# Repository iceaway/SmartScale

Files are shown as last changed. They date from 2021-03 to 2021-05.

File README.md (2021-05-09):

# SmartScale
## What is it
What is SmartScale? The idea for a "smart scale" came about when I was 
grinding coffee and got tired of moving the portafilter between my grinder
and scale to measure my exact amount. I figured it should be quite easy to
hook up an ESP8266 to a load cell for measuring the amount of coffee, and
control the grinder directly in some way. For this initial prototype I have
connected my ESP8266 to a 1 kg load cell via a cheap HX711 breakout board,
and to a relay for controlling the grinder. The way it operates is that
I will have to hold the manual grind button on the grinder, and the "SmartScale"
will cut the power to the grinder when the desired amount is measured. The 
mains power stuff is enclosed in a plastic box, and the load cell is mounted to
a very simple 3D-printed platform.

## Hardware hookup
### Prototype
Connect the ESP8266 to the SCK and DOUT pins on the HX711 breakout board (I use
[this](https://www.electrokit.com/produkt/hx711-lastcellsforstarkare-monterad-pa-kort/) 
particular board). The pins on the ESP8266 can be configured in the `config.h`
file. Connect another pin on the ESP8266 to a relay (I use something like 
[this](https://www.electrokit.com/produkt/relamodul-5v/)) along with power
and ground. Make sure the relay can be controlled by a 3.3V signal, if you 
intend to power it directly from the ESP8266.

Here is what the prototype on my desk looks like:

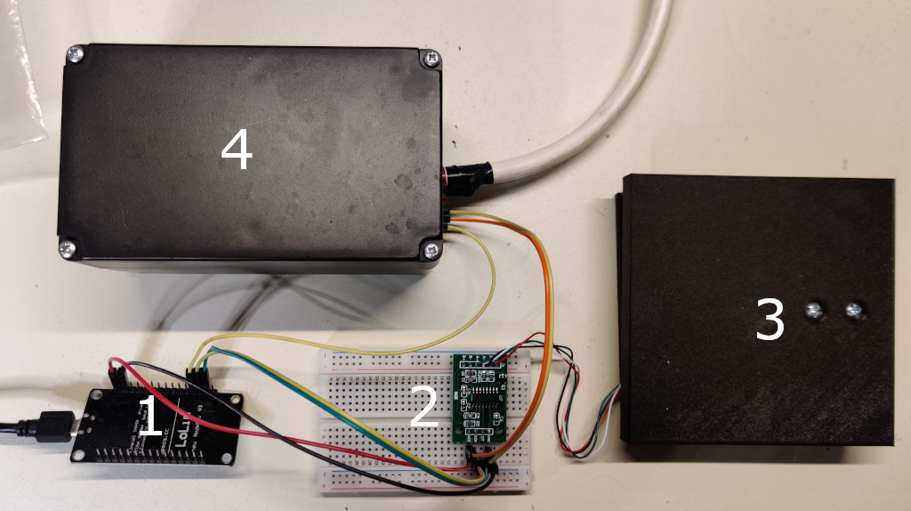
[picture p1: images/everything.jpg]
components making up the smart scale project


1. NodeMCUv3 microcontroller
2. HX711 breakout board
3. 3D-printed scale platform with 1 kg load cell inside
4. Plastic box I had lying around for keeping the mains voltage safely away from poking fingers. The white cable has a regular power socket on the end for connecting the power plug of the grinder. On the side of the box (out of view) is a [C14](https://www.electrokit.com/produkt/natbrunn-c14-jordad-flatstift-6-3mm/) socket for connecting the mains voltage. Inside this box the relay is located.

The connections are as follows:
| MCU | HX177 | RELAY |
| --- | ----- | ----- |
| D1  | DOUT/DT | NC  |
| D2  | SCK | NC |
| D3  | NC | S/Control |
| 3.3V | VCC | VCC |
| GND | GND | GND |
### Version 2
This is how version two of the project turned out, once I did a 3D-print of
the scale platform that also fit the MCU + HX711 board, and the box containing
the mains power and relay. The power box contains the relay and the guts of a
wall-charger with a USB connector. The cable between the power box and scale
platform has +5V, GND and the signal from the MCU that controls the relay. The
power box is fed from by a C14 connector. I initially thought that I would power 
the MCU separately with a USB cable, but decided against that to reduce the
cable clutter). 
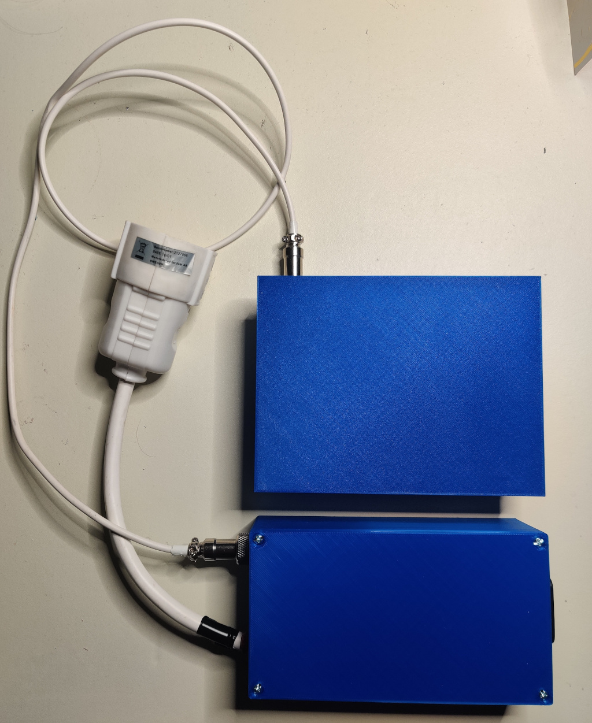
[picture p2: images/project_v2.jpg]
version 2 of the project with 3d-printed enclosures


## Usage
When powered on the first time, no wifi-credentials will be stored in the
ESP8266, and it will start an Access Point called "SmartScale" that you can
connect to using your phone or tablet. Once connected navigate to 
`http://192.168.4.1` and configure the WiFi you want to use. After configuration
the scale will restart, and you can connect to it on your regular WiFi. For now,
mDNS is not supported, so you will have to check the IP-address on the serial
console or on your DHCP server. On the web page, it is possible to manually 
tare the scale, see the current weight, configure the target weight (at which
weight the relay will be toggled), and reset the relay for making another run.
Below is a screenshot of the webpage on a mobile device.

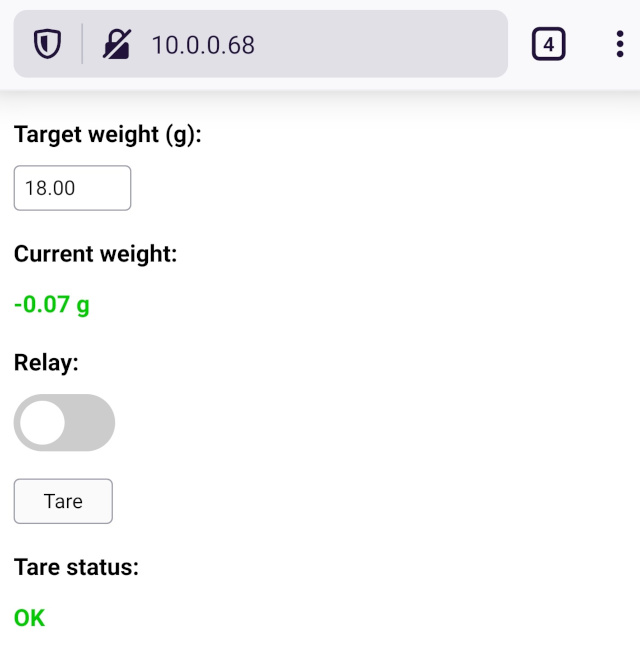
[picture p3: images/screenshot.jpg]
smartscale screenshot


The serial inteface has some basic configuration
options, including calibration, which is not available on the web page yet. 
When connected to the serial terminal (9600 baud), press 'h' to get some
information on the possible commands.

## Todo
### Code

- [ ] Enable calibration from the web page
- [ ] Impove web page design
- [x] Add support for mDNS

### Hardware

- [x] Upload FreeCad files for platform 
- [x] Improve CAD design to fit the ESP8266 and HX711 board
- [x] Design and print an enclosure for the mains power stuff and MCU
- [ ] Design a custom PCB for mounting the ESP8266 and HX711 parts

### Misc

- [x] Add photos of the scale and how it is set up / connected
- [x] Add screenshots

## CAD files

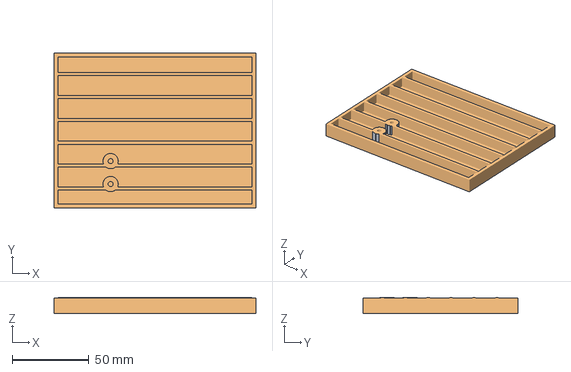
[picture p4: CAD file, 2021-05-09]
hardware/mechanics/top.FCStd
132.0 x 101.0 x 10.5 mm
Body (Meshed)

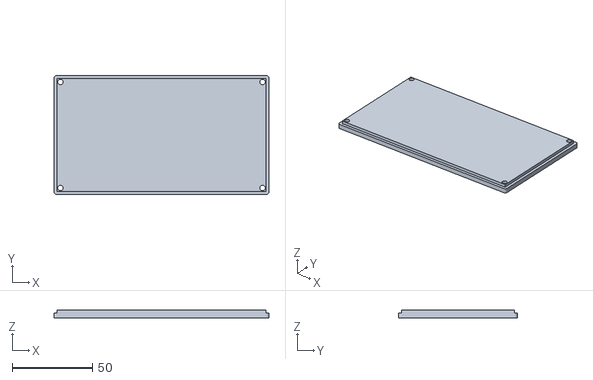
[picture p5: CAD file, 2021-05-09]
hardware/mechanics/pb_top.stl
134.0 x 74.0 x 4.90

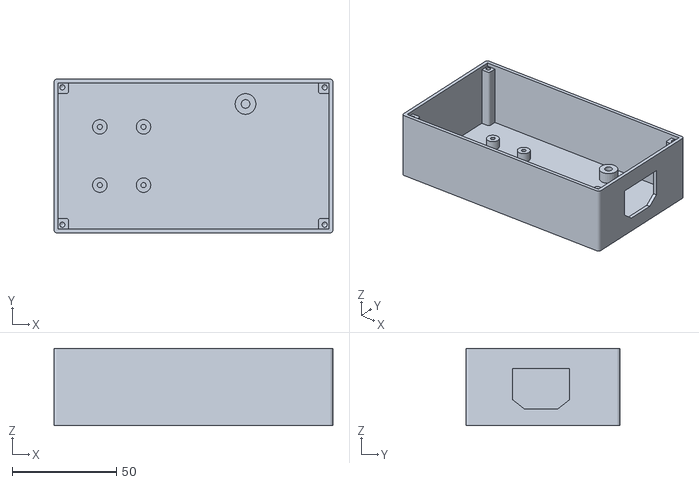
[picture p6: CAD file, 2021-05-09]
hardware/mechanics/pb_bottom.stl
134.0 x 74.0 x 37.0

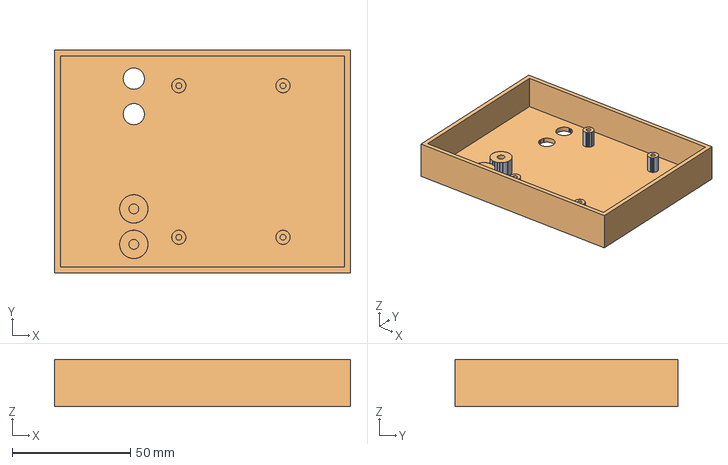
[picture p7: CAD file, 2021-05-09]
hardware/mechanics/bottom.FCStd
125.0 x 94.0 x 20.0 mm
Body (Meshed)

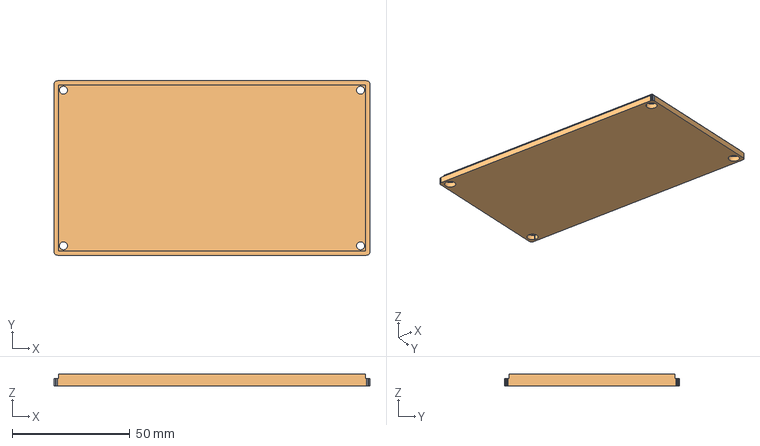
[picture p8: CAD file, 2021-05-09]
hardware/mechanics/powerbox_top.FCStd
134.0 x 74.0 x 4.90 mm
Body (Meshed)

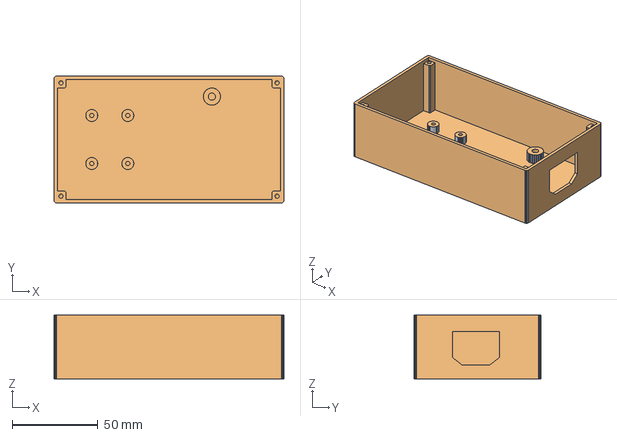
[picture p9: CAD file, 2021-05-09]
hardware/mechanics/powerbox_bottom.FCStd
134.0 x 74.0 x 37.0 mm
Body (Meshed)

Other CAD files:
hardware/mechanics/bottom.stl
hardware/mechanics/top.stl

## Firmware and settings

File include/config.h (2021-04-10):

#ifndef Config_h
#define Config_h

#define HTTP_PORT   80

/* Pins to use for the hardware connections */
#define HX711_DOUT  4 /* D2 */
#define HX711_SCK   5 /* D3 */
#define RELAY_PIN   0 /* D3 */

/* Default values */
#define DEFAULT_SETPOINT                18.0f
#define DEFAULT_CALIBRATION_VALUE       696.0f
#define DEFAULT_TIMER_THRESHOLD         0.5f

/* EEPROM memory map */
#define EEP_SIZE                        512
#define EEP_CALIBRATION_VALUE_ADDR      0
#define EEP_CALIBRATION_VALUE_SIZE      4l
#define EEP_SETPOINT_ADDR               ((EEP_CALIBRATION_VALUE_ADDR) + (EEP_CALIBRATION_VALUE_SIZE))
#define EEP_SETPOINT_SIZE               4
#define EEP_TIMER_THRESHOLD_ADDR        ((EEP_SETPOINT_ADDR) + (EEP_TIMER_THRESHOLD_SIZE))
#define EEP_TIMER_THRESHOLD_SIZE        4
#define EEP_CRC32_ADDR                  ((EEP_SIZE) - 4)
#define EEP_CRC32_SIZE                  4

/* Limit the weight setpoint */
#define WEIGHT_LIMIT_MIN    5.0f
#define WEIGHT_LIMIT_MAX    30.0f

#endif

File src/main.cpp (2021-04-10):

#include <Arduino.h>
#include <ESP8266WebServer.h>
#include <ESP8266mDNS.h>
#include <FS.h>
#include <LittleFS.h>
#if defined(ESP8266) || defined(ESP32) || defined(AVR)
#include <EEPROM.h>
#endif
#include <CRC32.h>
#include "webserver.h"
#include "loadcell.h"
#include "control.h"
#include "config.h"
#include "eeprom.h"

/* 
 * TODO:
 * - Calibrate from web page
 * - Make webpage look nicer
 * - mDNS / DNS server support
 */

void setup(void)
{
    String mdnsname = "SmartScale";

    Serial.begin(9600);
    /* Delay here to not miss any output as we go from upload mode
     * to monitor mode.
     */
    delay(500);
    Serial.println();
    Serial.println("Starting...");
    /* Check EEPROM validity */
    Serial.println("Checking EEPROM...");
    eeprom_setup();
    Serial.println("Setting up wifi and webserver...");
    webserver_setup();
    Serial.println("Setting up load cell...");
    loadcell_setup();
    Serial.println("Setting up Control loop..");
    control_setup();
    Serial.println("Setting up filesystem...");
    if (!LittleFS.begin()) {
        Serial.println("Failed to setup LittleFS!");
    }

    if (MDNS.begin(mdnsname)) {
        Serial.print("mDNS service started: ");
        Serial.println(mdnsname);
        MDNS.addService("http", "tcp", HTTP_PORT);
    } else {
        Serial.println("Failed to start mDNS service");
    }

    Serial.println("Setup complete!");
}

void loop(void)
{
    loadcell_loop();
    control_loop();
    MDNS.update();
}

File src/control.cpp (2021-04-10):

#include <Arduino.h>
#include <EEPROM.h>

#include "control.h"
#include "loadcell.h"
#include "config.h"
#include "eeprom.h"

#define PRINT_INTERVAL  1000

static unsigned int g_timer_start = 0;
static unsigned int g_timer_stop = 0;

enum timer_state_e {
        WAITING,
        RUNNING,
        STOPPED
    };

static enum timer_state_e g_tstate = WAITING;

void control_setup(void)
{
    pinMode(RELAY_PIN, OUTPUT);
    digitalWrite(RELAY_PIN, 0);
}

bool control_get_relay(void)
{
    return (digitalRead(RELAY_PIN) == HIGH);
}

void control_set_relay(void)
{
    digitalWrite(RELAY_PIN, 1);
}

void control_reset_relay(void)
{
    digitalWrite(RELAY_PIN, 0);
}

unsigned int control_get_elapsed_time(void)
{
#ifdef DEBUG
    Serial.print("t_state = ");
    Serial.println(g_tstate);
    Serial.print("g_timer_start = ");
    Serial.println(g_timer_start);
    Serial.print("g_timer_stop = ");
    Serial.println(g_timer_stop);

#endif
    if (g_tstate == RUNNING)
        return millis() - g_timer_start;
    else if (g_tstate == STOPPED)
        return g_timer_stop - g_timer_start;
    else
        return 0;
}

void control_loop(void)
{
    static unsigned int t = millis();

    if (loadcell_get_weight() >= eeprom_setpoint_get()) {
         if (millis() > t + PRINT_INTERVAL) { 
            Serial.println("Weight setpoint exceeded.");
            t = millis();
        }
        control_set_relay();
    }

    switch (g_tstate) {
    case WAITING:
        if (loadcell_get_weight() >= eeprom_timer_threshold_get()) {
           g_timer_start = millis();
           g_tstate = RUNNING;
        }
        break;

    case RUNNING:
        if (loadcell_get_weight() >= eeprom_setpoint_get()) {
            g_timer_stop = millis();
            g_tstate = STOPPED;
        }

    case STOPPED:
        if (loadcell_get_weight() <= eeprom_timer_threshold_get()) {
            g_tstate = WAITING;
        }
        break;        
    }
}

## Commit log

2021-03-24 Added a configuration portal if no wifi credentials are saved Added menu to the serial terminal if 'h' is entered. Menu item for resetting wifi credentials.
    [loadcell.cpp, webserver.cpp]
2021-03-24 Improved interrupt handling Fixed warnings
    [control.cpp, loadcell.cpp, main.cpp]
2021-03-25 Some refactoring Moved config settings to config.h Added mDNS support Added FreeCAD files for scale platform Added README
    [bottom.FCStd, bottom.stl, top.FCStd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]
2021-03-26 Added prototype hardware desrscription
2021-04-10 eeprom: improve behavior if invalid data for a parameter in eeprom
    web:
    move style sheets to another file
    show the elapsed time for the grinding process
    disable tare button while taring
    control:
    time the grinding process
2021-05-09 Updated README with latest developments. Added mechanics for the power box.
    [powerbox_bottom.FCStd, powerbox_top.FCStd]
2021-05-09 Updated design of the scale platform, .stl files for the power box
    [bottom.FCStd, pb_bottom.stl, pb_top.stl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]
2021-05-09 Updated .stl files for the scale platform
    [bottom.stl, top.stl]
